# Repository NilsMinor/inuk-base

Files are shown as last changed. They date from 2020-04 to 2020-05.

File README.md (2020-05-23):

# Inuk base

This board is used in my open source smart garden light project. It is a 2 layer 70 mm x 100 mm design and serves as an NRF52 module carrier.
The board is powered by one 18650 rechargeable lipo and charged by an TP4056 module with a 6V solar cell. The light interface can controll up to five pwm controlled 3W LEDs.

#### Pin description

| Pin |  Function  | Note |
| ----- | :---: | ---: |
| P0.26 | LED D2 | high active |
| P0.27 | LED D3 | high active |
| P0.25 | BUTTON SW2 | low active |
| P0.06 |  UART TX | |
| P0.08 |  UART RX | |
| P0.07 |  UART RTS  | |
| P0.05 |  UART CTS  | |
| P0.02 | AIN0 | analog input - VBAT |
| P0.03 | AIN1 | analog input - VSOLAR |
| P0.04 | AIN2 | analog input |
| P0.28 | AIN4 | analog input - VLDR |
| P0.29 | AIN5 | analog input |
| P0.30 | AIN6 | analog input |
| P0.31 | AIN7 | analog input |
| P0.11 | LIO1 | pwm output led 1 |
| P0.12 | LIO2 | pwm output led 2 |
| P0.13 | LIO3 | pwm output led 3 |
| P0.14 | LIO4 | pwm output led 4 |
| P0.15 | LIO5 | pwm output led 5 |
| P0.16 | PIR INPUT  | pir input - high active |

#### Software

The inuk-base board is equipped with an E73-2G4M04S1B module that contains an nrf52832 SoC from nordic semiconductor. The nrf52832 bluetooth SoC comes with cortex-m4, 64K RAM and 512K ROM.

##### Note

It might happen that the E73 module comes with locked UICR. In order to unlock the flash download nrfjprog from nordic. Run the following command:

```
nrfjprog --recover
```

The output should then look like :

```
Recovering device. This operation might take 30s.
Erasing user code and UICR flash areas.
```

###### Click on the image below to see the gerber files

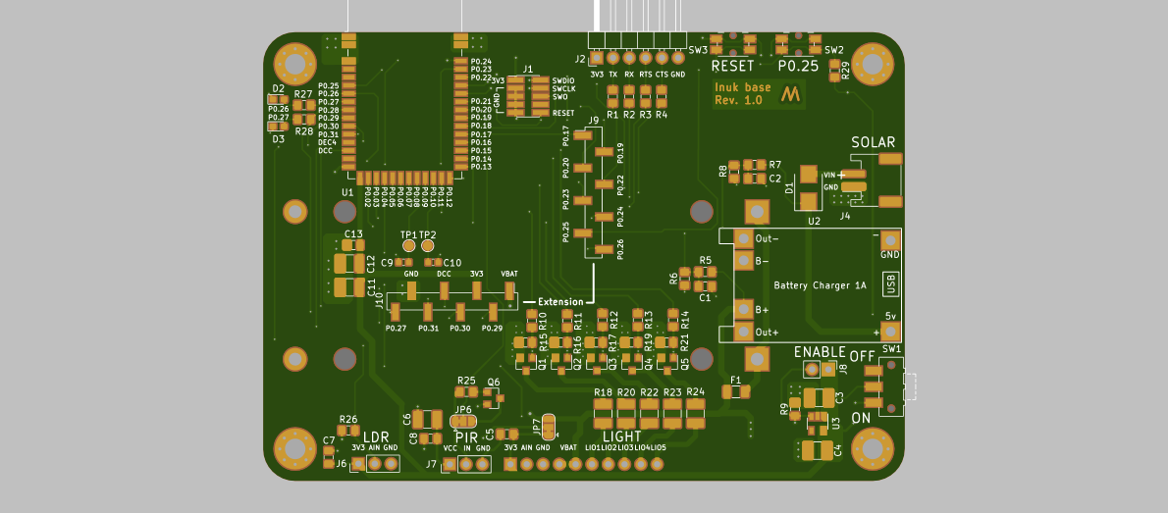
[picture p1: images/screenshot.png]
[](https://stackrate.de/viewer?stackId=Oa3Chhu8g)

###### Needs to be changed for version 2

- Remove direct GND connection poligons on E73 module. The direct GND connection is difficult to solder and needs
- Add (+) symbol to battery connector
- The DCDC on the NRF52 module is not supported, this should be changed in the next version.

##View in 3D
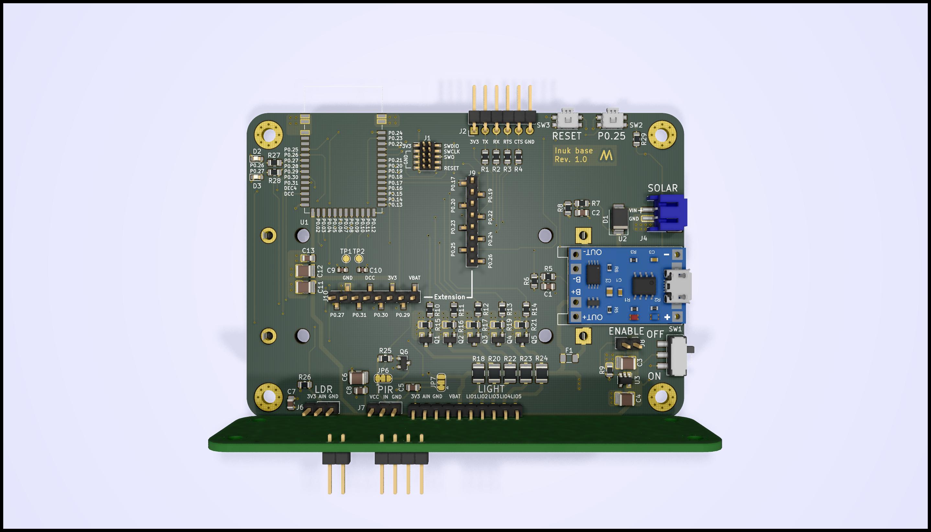
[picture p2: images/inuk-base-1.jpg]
3D Image 1

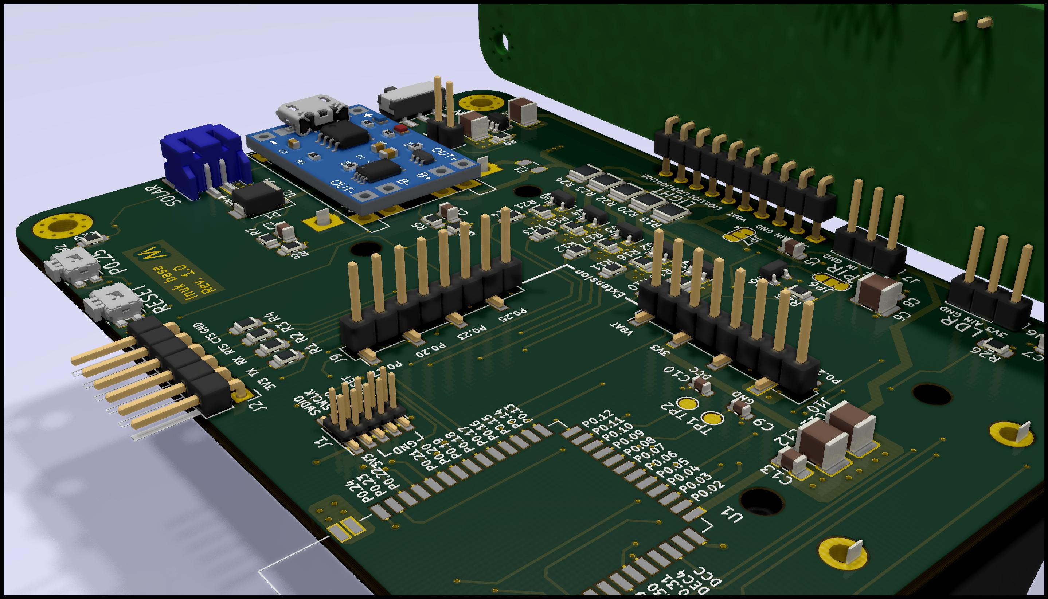
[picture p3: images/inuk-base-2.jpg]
3D Image 2

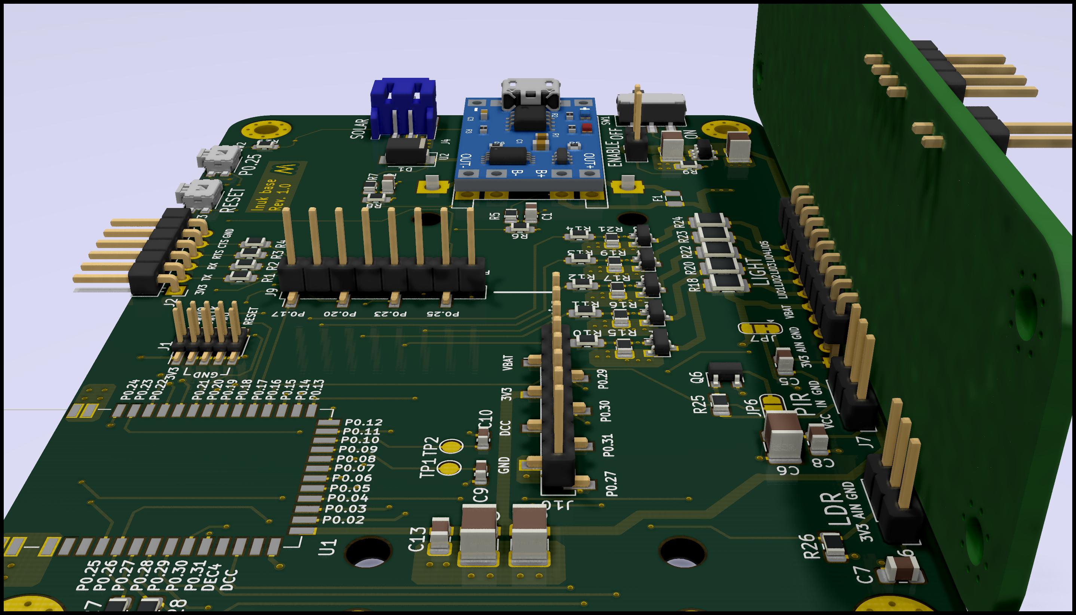
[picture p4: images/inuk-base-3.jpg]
3D Image 3


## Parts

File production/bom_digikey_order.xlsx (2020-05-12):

Comment | Designator | Footprint | Count | MPN
Fuse | F1 | Fuse:Fuse_1206_3216Metric | 1 | 0466002.NRHF
100R | R1,R2,R3,R4,R10,R11,R12,R13,R14 | Resistor_SMD:R_0805_2012Metric_Pad1.15x1.40mm_HandSolder | 9 | 0805W8F1000T5E
1k | R28,R27,R25 | Resistor_SMD:R_0805_2012Metric_Pad1.15x1.40mm_HandSolder | 3 | 0805W8F1001T5E
100k | R9,R16,R17,R19,R21,R15,R29,R26 | Resistor_SMD:R_0805_2012Metric_Pad1.15x1.40mm_HandSolder | 8 | 0805W8F1003T5E
2M | R6,R7 | Resistor_SMD:R_0805_2012Metric_Pad1.15x1.40mm_HandSolder | 2 | 0805W8F2004T5E
806k | R5,R8 | Resistor_SMD:R_0805_2012Metric_Pad1.15x1.40mm_HandSolder | 2 | 0805W8F8063T5E
0R5 | R24,R23,R22,R20,R18 | Resistor_SMD:R_1210_3225Metric_Pad1.42x2.65mm_HandSolder | 5 | 1210W3F500LT5E
LED | D3,D2 | LED_SMD:LED_0603_1608Metric_Pad1.05x0.95mm_HandSolder | 2 | 19-217/GHC-YR1S2/3T
AP2112K-3.3 | U3 | Package_TO_SOT_SMD:SOT-23-5 | 1 | AP2112K-3.3TRG1
B230-13-F | D1 | Diode_SMD:D_SMB | 1 | B230-13-F
1nF | C1,C2 | Capacitor_SMD:C_0805_2012Metric_Pad1.15x1.40mm_HandSolder | 2 | CL21B102KBCNNNC
100nF | C5,C13,C8,C7 | Capacitor_SMD:C_0805_2012Metric_Pad1.15x1.40mm_HandSolder | 4 | CL21B104KCFNNNE
10uF | C3,C4,C11,C12,C6 | Capacitor_SMD:C_1210_3225Metric_Pad1.42x2.65mm_HandSolder | 5 | CL31A106KBHNNNE
DMG3406L | Q2,Q3,Q4,Q5,Q1 | Package_TO_SOT_SMD:SOT-23 | 5 | DMG3420U-7
Battery_Cell | BT1,BT2 | Battery:BatteryHolder_MPD_BH-18650-PC2 | 1 | BK-18650-PC2
Conn_02x05_Odd_Even | J1 | Connector_PinHeader_1.27mm:PinHeader_2x05_P1.27mm_Vertical_SMD | 1 | FTSH-105-01-L-DV
Conn_01x06 | J2 | Connector_PinHeader_2.54mm:PinHeader_1x06_P2.54mm_Horizontal | 1 | 61301011121
Conn_01x02_Male | J4,J3 | Connector_JST:JST_PH_S2B-PH-SM4-TB_1x02-1MP_P2.00mm_Horizontal | 2 | S2B-PH-SM4-TB
Conn_01x08 | J5 | Custom:LED_shield | 1 | 61301211121
Conn_01x02_Male | J8 | Connector_PinHeader_2.54mm:PinHeader_1x02_P2.54mm_Vertical | 1 | 61301211121
Conn_01x08_Male | J9,J10 | Connector_PinHeader_2.54mm:PinHeader_1x08_P2.54mm_Vertical_SMD_Pin1Left | 1 | 61001618221 | 16 pin MPN selected to break
Conn_01x03_Male | J7,J6 | Connector_PinHeader_2.54mm:PinHeader_1x03_P2.54mm_Vertical | 2
SW_Push_SPDT | SW1 | Button_Switch_SMD:SW_SPDT_CK-JS102011SAQN | 1 | JS102011SAQN
SW_Push | SW3,SW2 | Button_Switch_SMD:Panasonic_EVQPUL_EVQPUC | 2 | EVQ-PUC02K

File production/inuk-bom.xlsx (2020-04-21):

Comment | Designator | Footprint | LCSC | LCSC | MPN
Fuse | F1 | Fuse:Fuse_1206_3216Metric |  | C3105 | 0466002.NRHF
100R | R1,R2,R3,R4,R10,R11,R12,R13,R14 | Resistor_SMD:R_0805_2012Metric_Pad1.15x1.40mm_HandSolder |  | C17408 | 0805W8F1000T5E
1k | R28,R27,R25 | Resistor_SMD:R_0805_2012Metric_Pad1.15x1.40mm_HandSolder |  | C17513 | 0805W8F1001T5E
100k | R9,R16,R17,R19,R21,R15,R29,R26 | Resistor_SMD:R_0805_2012Metric_Pad1.15x1.40mm_HandSolder |  | C17407 | 0805W8F1003T5E
2M | R6,R7 | Resistor_SMD:R_0805_2012Metric_Pad1.15x1.40mm_HandSolder |  | C26112 | 0805W8F2004T5E
806k | R5,R8 | Resistor_SMD:R_0805_2012Metric_Pad1.15x1.40mm_HandSolder |  | C63494 | 0805W8F8063T5E
0R5 | R24,R23,R22,R20,R18 | Resistor_SMD:R_1210_3225Metric_Pad1.42x2.65mm_HandSolder |  | C21355 | 1210W3F500LT5E
LED | D3,D2 | LED_SMD:LED_0603_1608Metric_Pad1.05x0.95mm_HandSolder |  | C72043 | 19-217/GHC-YR1S2/3T
AP2112K-3.3 | U3 | Package_TO_SOT_SMD:SOT-23-5 |  | C51118 | AP2112K-3.3TRG1
B230-13-F | D1 | Diode_SMD:D_SMB |  | C110482 | B230-13-F
1nF | C1,C2 | Capacitor_SMD:C_0805_2012Metric_Pad1.15x1.40mm_HandSolder |  | C46653 | CL21B102KBCNNNC
100nF | C5,C13,C8,C7 | Capacitor_SMD:C_0805_2012Metric_Pad1.15x1.40mm_HandSolder |  | C28233 | CL21B104KCFNNNE
10uF | C3,C4,C11,C12,C6 | Capacitor_SMD:C_1210_3225Metric_Pad1.42x2.65mm_HandSolder |  | C13585 | CL31A106KBHNNNE
DMG3406L | Q2,Q3,Q4,Q5,Q1 | Package_TO_SOT_SMD:SOT-23 |  | C154722 | DMG3420U-7
Battery_Cell | BT1,BT2 | Battery:BatteryHolder_MPD_BH-18650-PC2 |  |  | BK-18650-PC2
Conn_02x05_Odd_Even | J1 | Connector_PinHeader_1.27mm:PinHeader_2x05_P1.27mm_Vertical_SMD |  |  | FTSH-105-01-L-DV
Conn_01x06 | J2 | Connector_PinHeader_2.54mm:PinHeader_1x06_P2.54mm_Horizontal |  |  | 61301011121
Conn_01x02_Male | J4,J3 | Connector_JST:JST_PH_S2B-PH-SM4-TB_1x02-1MP_P2.00mm_Horizontal |  |  | S2B-PH-SM4-TB
Conn_01x08 | J5 | Custom:LED_shield |  |  | 61301211121
Conn_01x02_Male | J8 | Connector_PinHeader_2.54mm:PinHeader_1x02_P2.54mm_Vertical |  |  | 61301211121
Conn_01x08_Male | J9,J10 | Connector_PinHeader_2.54mm:PinHeader_1x08_P2.54mm_Vertical_SMD_Pin1Left |  |  | 61001618221 | 16 pin MPN selected to break
Conn_01x03_Male | J7,J6 | Connector_PinHeader_2.54mm:PinHeader_1x03_P2.54mm_Vertical
BC817 | Q6 | Package_TO_SOT_SMD:SOT-23 |  |  |  | NC
SW_Push_SPDT | SW1 | Button_Switch_SMD:SW_SPDT_CK-JS102011SAQN
SW_Push | SW3,SW2 | Button_Switch_SMD:Panasonic_EVQPUL_EVQPUC
TestPoint | TP1,TP2 | TestPoint:TestPoint_Pad_D1.5mm
E73-2G4M04S-52832 | U1 | RF_Module:E73-2G4M04S |  |  | ordered 7 | https://www.amazon.de/gp/product/B07WRKK521/ref=ppx_od_dt_b_asin_title_s00?ie=UTF8&psc=1
TP4056-module | U2 | Module:TP4056-module |  |  | ordered | https://www.ebay.de/itm/TP4056-USB-C-Neu-Li-Ion-Lademodul-5V-1A-18650-Laderegler-Charger-LIPO-Board/392521487361
Logo_NM | U4 | Custom:Logo_NM |  |  |  | NC
NC | C10,C9 | Capacitor_SMD:C_0603_1608Metric |  |  |  | NC
MountingHole | H4,H3,H2,H1 | MountingHole:MountingHole_3.2mm_M3_Pad_Via |  |  |  | NC
Jumper_NO_Small | JP1,JP2,JP3,JP4,JP5 | Jumper:SolderJumper-2_P1.3mm_Open_RoundedPad1.0x1.5mm |  |  |  | NC
SolderJumper_3_Bridged12 | JP7,JP6 | Jumper:SolderJumper-3_P1.3mm_Bridged12_RoundedPad1.0x1.5mm |  |  |  | NC
AM312 |  | PIR sensor extern | 1 |  | ordered 5 | https://www.amazon.de/gp/product/B07RJQMD9G/ref=ppx_yo_dt_b_asin_title_o00_s00?ie=UTF8&psc=1
3W power LEDs |  | High Power LEDs |  | 5 | ordered 100 | https://www.amazon.de/gp/product/B07BVTNS6Y/ref=ppx_yo_dt_b_asin_title_o00_s00?ie=UTF8&psc=1

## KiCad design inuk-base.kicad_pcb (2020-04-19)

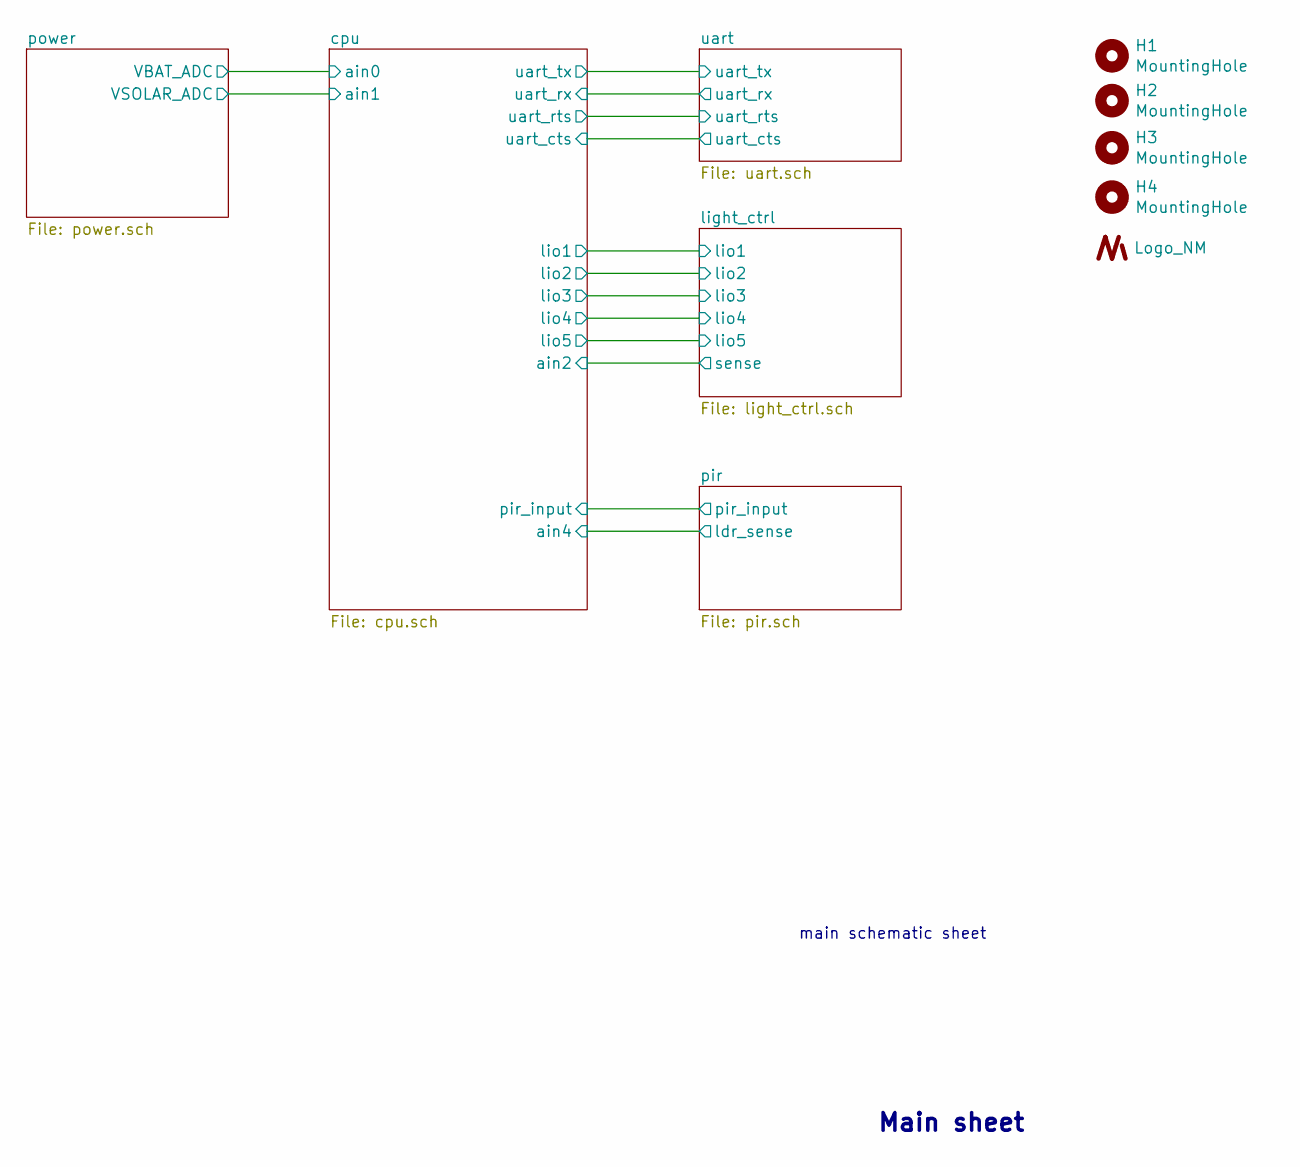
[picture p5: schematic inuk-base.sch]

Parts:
H1, H2, H3, H4: MountingHole; MountingHole_3.2mm_M3_Pad_Via
U4: Logo_NM

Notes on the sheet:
Main sheet
main schematic sheet

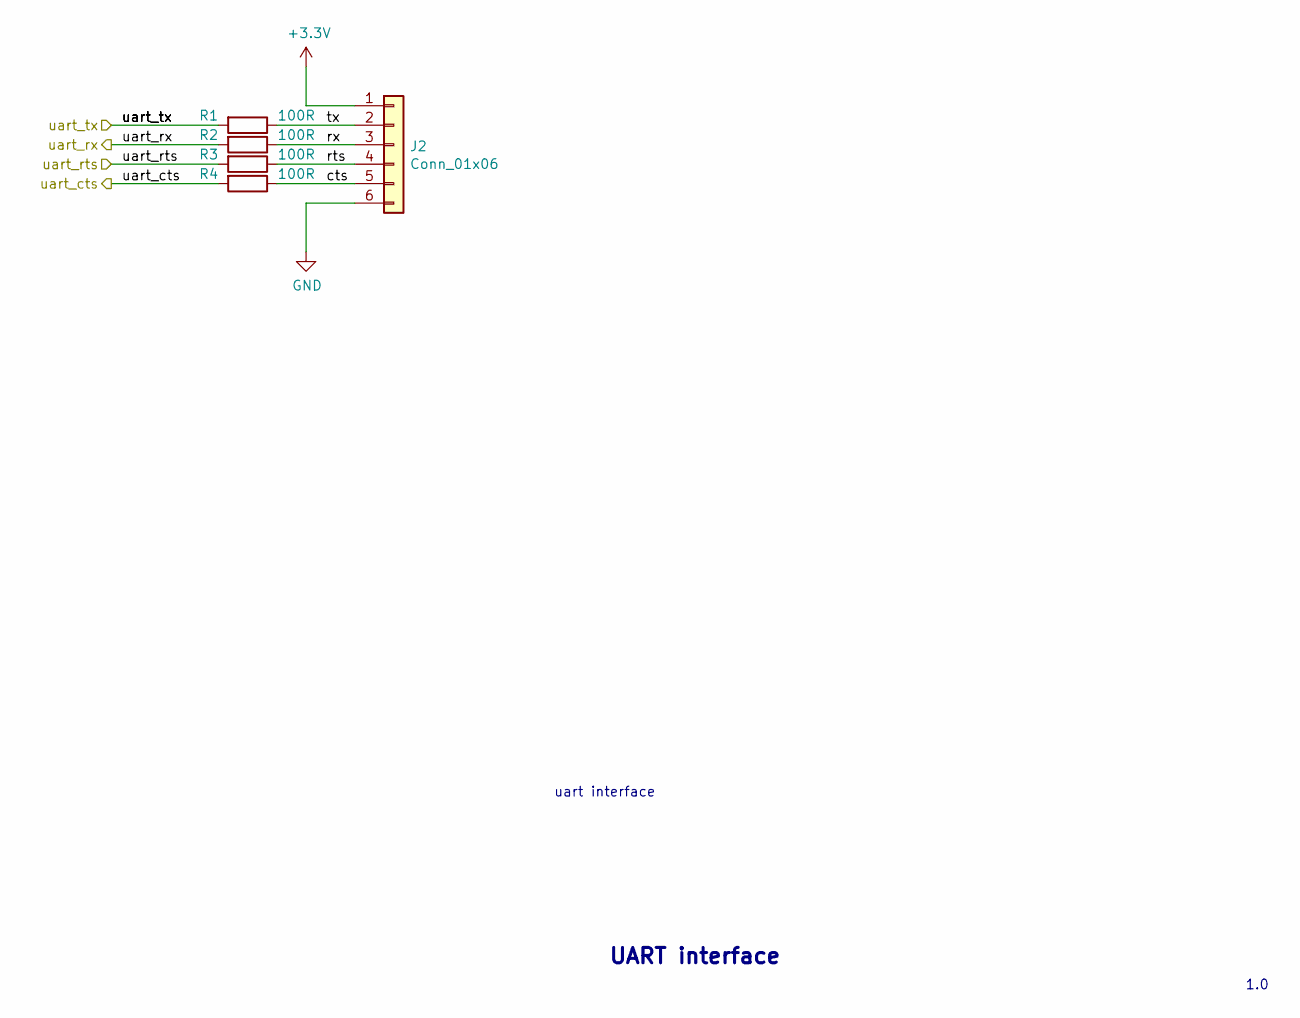
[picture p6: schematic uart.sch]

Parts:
J2: Conn_01x06; PinHeader_1x06_P2.54mm_Horizontal
R1, R2, R3, R4: 100R; R_0805_2012Metric_Pad1.15x1.40mm_HandSolder; MPN 0805W8F1000T5E; LCSC C17408

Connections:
+3V3: J2.1; also elsewhere on the board
/cpu/uart_cts: R4.2; also elsewhere on the board
/cpu/uart_rts: R3.2; also elsewhere on the board
/cpu/uart_rx: R2.2; also elsewhere on the board
/cpu/uart_tx: R1.2; also elsewhere on the board
/uart/cts: J2.5, R4.1
/uart/rts: J2.4, R3.1
/uart/rx: J2.3, R2.1
/uart/tx: J2.2, R1.1
GND: J2.6; also elsewhere on the board

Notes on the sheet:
UART interface
uart interface
1.0

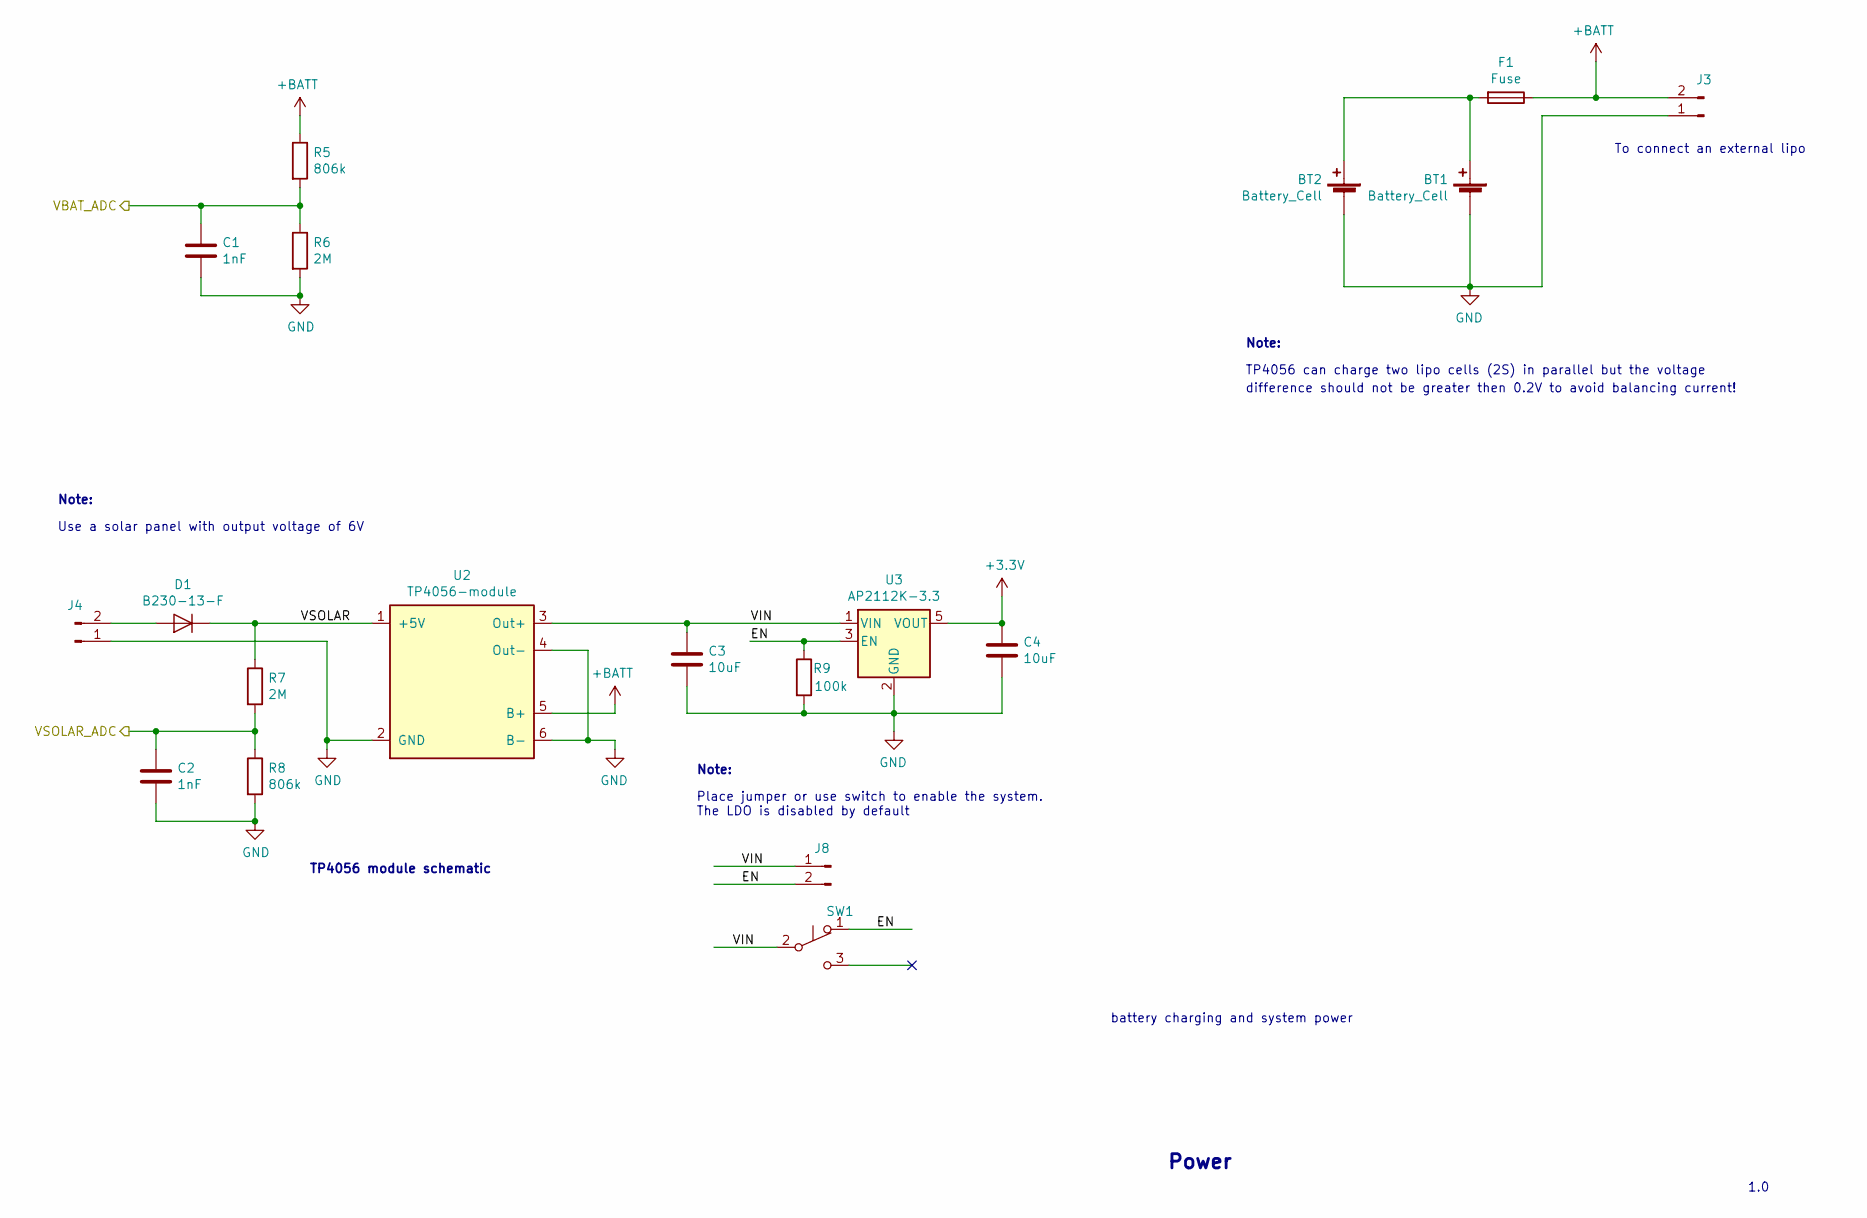
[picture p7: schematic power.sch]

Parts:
BT1, BT2: Battery_Cell; BatteryHolder_MPD_BH-18650-PC2
C1, C2: 1nF; C_0805_2012Metric_Pad1.15x1.40mm_HandSolder; MPN CL21B102KBCNNNC; LCSC C46653
C3, C4: 10uF; C_1210_3225Metric_Pad1.42x2.65mm_HandSolder; MPN CL31A106KBHNNNE; LCSC C13585
D1: B230-13-F; D_SMB; MPN B230-13-F; LCSC C110482
F1: Fuse; Fuse_1206_3216Metric; MPN 0466002.NRHF; LCSC C3105
J3, J4: Conn_01x02_Male; JST_PH_S2B-PH-SM4-TB_1x02-1MP_P2.00mm_Horizontal
J8: Conn_01x02_Male; PinHeader_1x02_P2.54mm_Vertical
R5, R8: 806k; R_0805_2012Metric_Pad1.15x1.40mm_HandSolder; MPN 0805W8F8063T5E; LCSC C63494
R6, R7: 2M; R_0805_2012Metric_Pad1.15x1.40mm_HandSolder; MPN 0805W8F2004T5E; LCSC C26112
R9: 100k; R_0805_2012Metric_Pad1.15x1.40mm_HandSolder; MPN 0805W8F1003T5E; LCSC C17407
SW1: SW_Push_SPDT; SW_SPDT_CK-JS102011SAQN
U2: TP4056-module
U3: AP2112K-3.3; SOT-23-5; MPN AP2112K-3.3TRG1; LCSC C51118

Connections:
+3V3: C4.1, U3.5 (VOUT); also elsewhere on the board
+BATT: F1.1, J3.2, R5.1, U2.5 (B+); also elsewhere on the board
/power/EN: J8.2, R9.1, SW1.1 (A), U3.3 (EN)
/power/VBAT_ADC: C1.1, R5.2, R6.1; also elsewhere on the board
/power/VIN: C3.1, J8.1, SW1.2 (B), U2.3 (Out+), U3.1 (VIN)
/power/VSOLAR: D1.1 (K), R7.1, U2.1 (+5V)
/power/VSOLAR_ADC: C2.1, R7.2, R8.1; also elsewhere on the board
GND: BT1.2 (-), BT2.2 (-), C1.2, C2.2, C3.2, C4.2, J3.1, J4.1, R6.2, R8.2, R9.2, U2.2 (GND), U2.4 (Out-), U2.6 (B-), U3.2 (GND); also elsewhere on the board
unnamed: BT1.1 (+), BT2.1 (+), F1.2
unnamed: D1.2 (A), J4.2

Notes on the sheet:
TP4056 can charge two lipo cells (2S) in parallel but the voltage
difference should not be greater then 0.2V to avoid balancing current!
Note:
Place jumper or use switch to enable the system. The LDO is disabled by default
TP4056 module schematic
Use a solar panel with output voltage of 6V
Power
battery charging and system power
To connect an external lipo
1.0

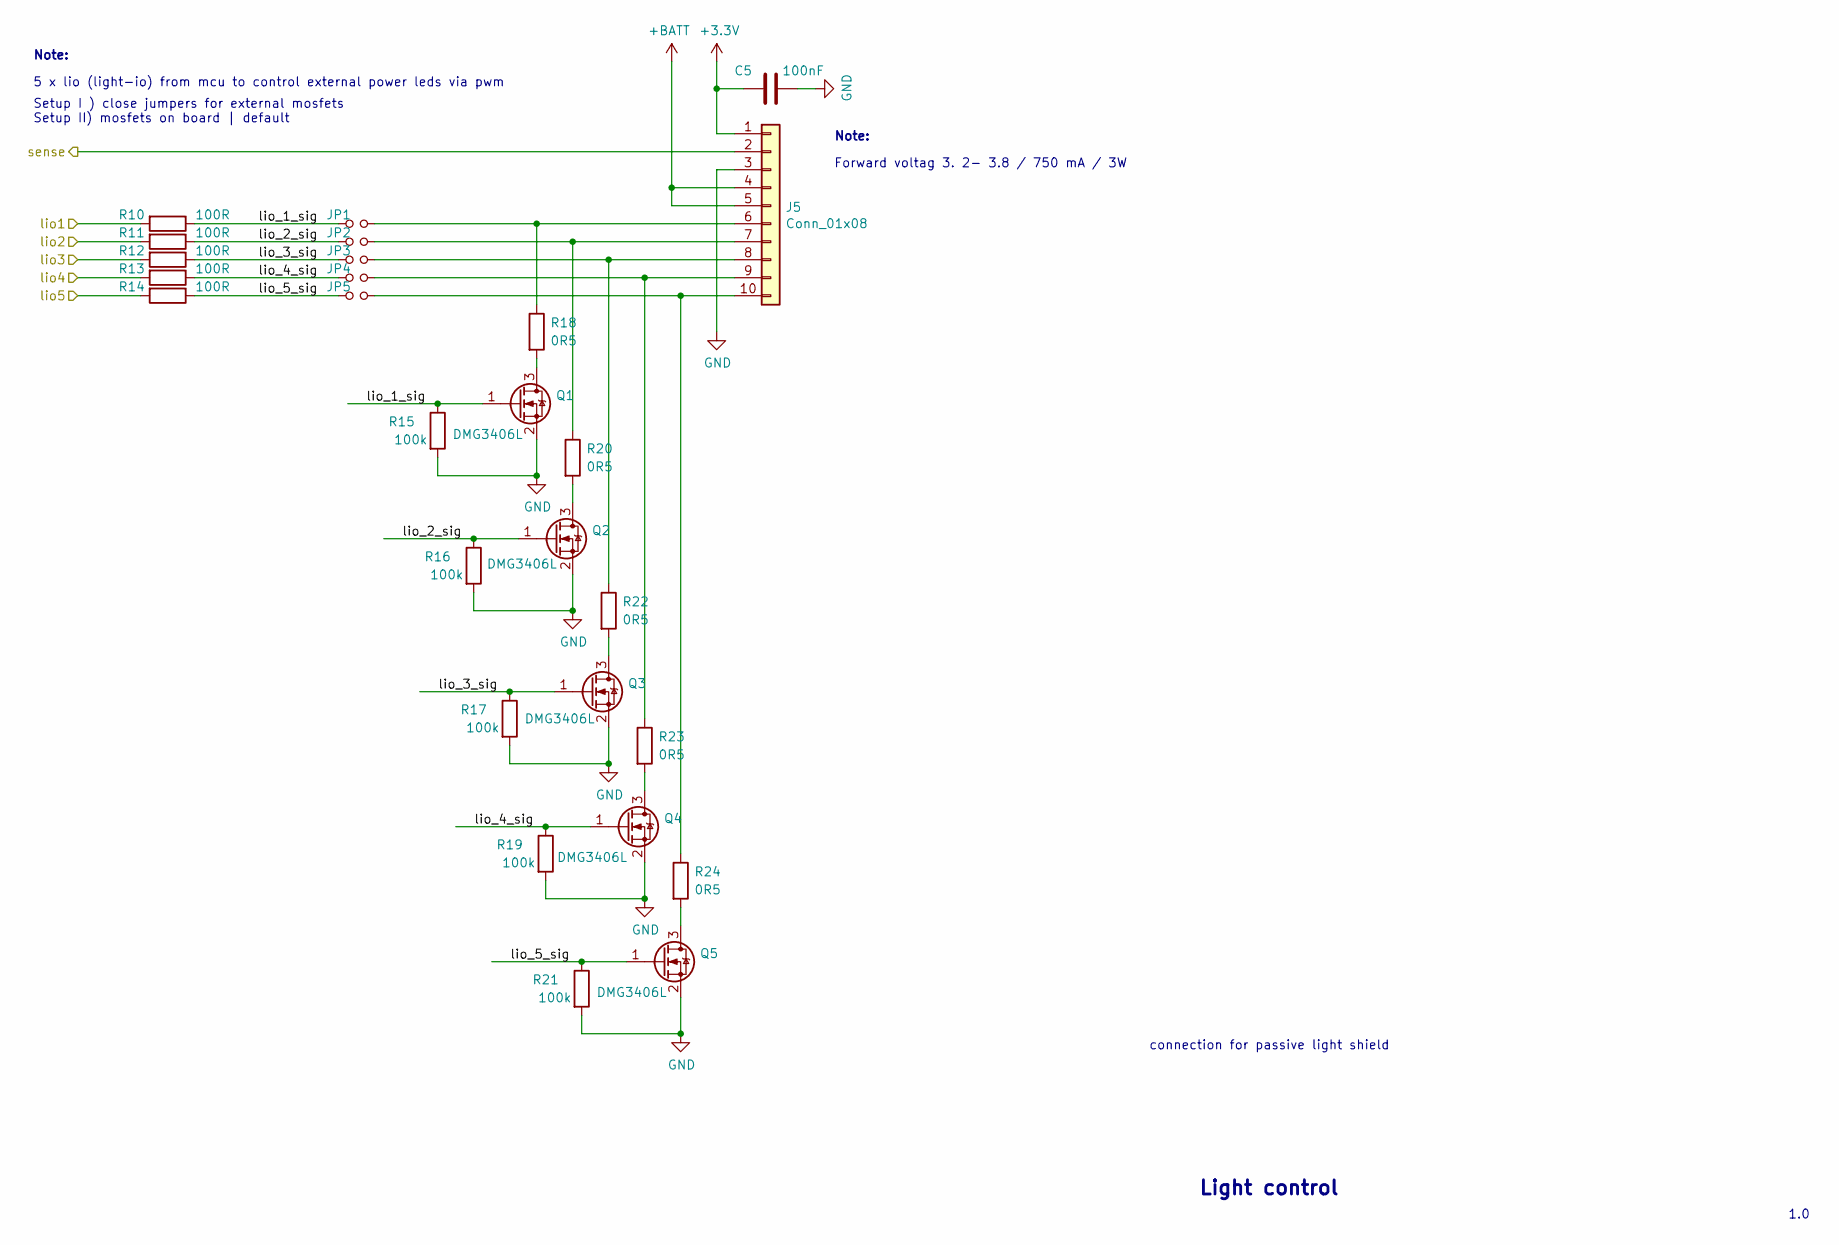
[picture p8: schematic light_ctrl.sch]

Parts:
C5: 100nF; C_0805_2012Metric_Pad1.15x1.40mm_HandSolder; MPN CL21B104KCFNNNE; LCSC C28233
J5: Conn_01x08; LED_shield
JP1, JP2, JP3, JP4, JP5: Jumper_NO_Small; SolderJumper-2_P1.3mm_Open_RoundedPad1.0x1.5mm
Q1, Q2, Q3, Q4, Q5: DMG3406L; SOT-23; MPN DMG3420U-7; LCSC C154722
R10, R11, R12, R13, R14: 100R; R_0805_2012Metric_Pad1.15x1.40mm_HandSolder; MPN 0805W8F1000T5E; LCSC C17408
R15, R16, R17, R19, R21: 100k; R_0805_2012Metric_Pad1.15x1.40mm_HandSolder; MPN 0805W8F1003T5E; LCSC C17407
R18, R20, R22, R23, R24: 0R5; R_1210_3225Metric_Pad1.42x2.65mm_HandSolder; MPN 1210W3F500LT5E; LCSC C21355

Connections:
+3V3: C5.1, J5.1; also elsewhere on the board
+BATT: J5.4, J5.5; also elsewhere on the board
/cpu/ain2: J5.2; also elsewhere on the board
/cpu/lio1: R10.2; also elsewhere on the board
/cpu/lio2: R11.2; also elsewhere on the board
/cpu/lio3: R12.2; also elsewhere on the board
/cpu/lio4: R13.2; also elsewhere on the board
/cpu/lio5: R14.2; also elsewhere on the board
/light_ctrl/lio_1_sig: JP1.1, Q1.1 (G), R10.1, R15.1
/light_ctrl/lio_2_sig: JP2.1, Q2.1 (G), R11.1, R16.1
/light_ctrl/lio_3_sig: JP3.1, Q3.1 (G), R12.1, R17.1
/light_ctrl/lio_4_sig: JP4.1, Q4.1 (G), R13.1, R19.1
/light_ctrl/lio_5_sig: JP5.1, Q5.1 (G), R14.1, R21.1
GND: C5.2, J5.3, Q1.2 (S), Q2.2 (S), Q3.2 (S), Q4.2 (S), Q5.2 (S), R15.2, R16.2, R17.2, R19.2, R21.2; also elsewhere on the board
unnamed: J5.6, JP1.2, R18.1
unnamed: J5.7, JP2.2, R20.1
unnamed: J5.8, JP3.2, R22.1
unnamed: J5.9, JP4.2, R23.1
unnamed: J5.10, JP5.2, R24.1
unnamed: Q1.3 (D), R18.2
unnamed: Q2.3 (D), R20.2
unnamed: Q3.3 (D), R22.2
unnamed: Q4.3 (D), R23.2
unnamed: Q5.3 (D), R24.2

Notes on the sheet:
5 x lio (light-io) from mcu to control external power leds via pwm
Note:
Forward voltag 3. 2- 3.8 / 750 mA / 3W
Setup I ) close jumpers for external mosfets Setup II) mosfets on board | default
Light control
connection for passive light shield
1.0

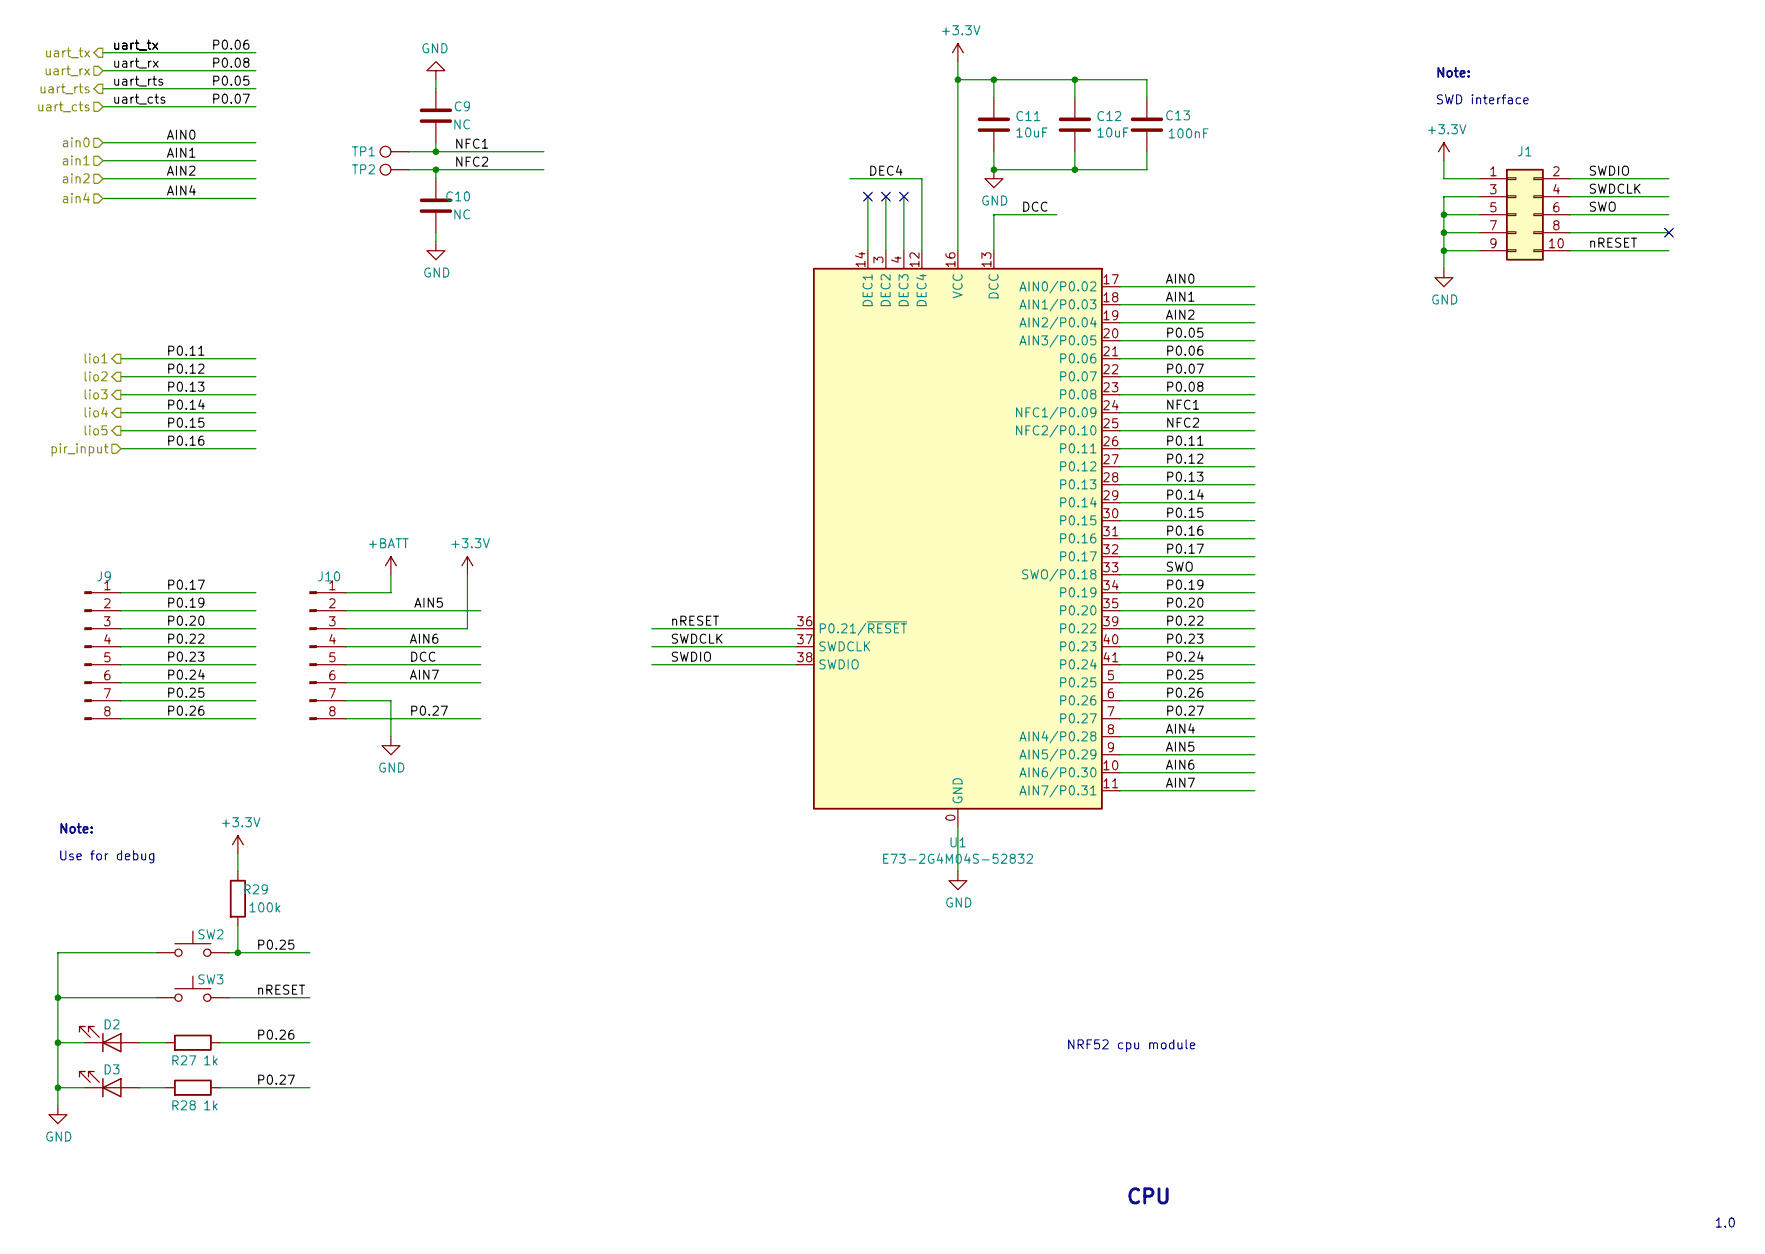
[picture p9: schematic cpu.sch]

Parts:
C9, C10: NC; C_0603_1608Metric
C11, C12: 10uF; C_1210_3225Metric_Pad1.42x2.65mm_HandSolder; MPN CL31A106KBHNNNE; LCSC C13585
C13: 100nF; C_0805_2012Metric_Pad1.15x1.40mm_HandSolder; MPN CL21B104KCFNNNE; LCSC C28233
D2, D3: LED; LED_0603_1608Metric_Pad1.05x0.95mm_HandSolder; MPN 19-217/GHC-YR1S2/3T; LCSC C72043
J1: Conn_02x05_Odd_Even; PinHeader_2x05_P1.27mm_Vertical_SMD
J9, J10: Conn_01x08_Male; PinHeader_1x08_P2.54mm_Vertical_SMD_Pin1Left
R27, R28: 1k; R_0805_2012Metric_Pad1.15x1.40mm_HandSolder; MPN 0805W8F1001T5E; LCSC C17513
R29: 100k; R_0805_2012Metric_Pad1.15x1.40mm_HandSolder; MPN 0805W8F1003T5E; LCSC C17407
SW2, SW3: SW_Push; Panasonic_EVQPUL_EVQPUC
TP1, TP2: TestPoint; TestPoint_Pad_D1.5mm
U1: E73-2G4M04S-52832; E73-2G4M04S

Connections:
+3V3: C11.1, C12.1, C13.2, J1.1, J10.3, R29.1, U1.16 (VCC); also elsewhere on the board
+BATT: J10.1; also elsewhere on the board
/cpu/AIN5: J10.2, U1.9 (AIN5/P0.29)
/cpu/AIN6: J10.4, U1.10 (AIN6/P0.30)
/cpu/AIN7: J10.6, U1.11 (AIN7/P0.31)
/cpu/DCC: J10.5, U1.13 (DCC)
/cpu/DEC4: U1.12 (DEC4)
/cpu/NFC1: C9.2, TP1.1, U1.24 (NFC1/P0.09)
/cpu/NFC2: C10.2, TP2.1, U1.25 (NFC2/P0.10)
/cpu/P0.17: J9.1, U1.32 (P0.17)
/cpu/P0.19: J9.2, U1.34 (P0.19)
/cpu/P0.20: J9.3, U1.35 (P0.20)
/cpu/P0.22: J9.4, U1.39 (P0.22)
/cpu/P0.23: J9.5, U1.40 (P0.23)
/cpu/P0.24: J9.6, U1.41 (P0.24)
/cpu/P0.25: J9.7, R29.2, SW2.2, U1.5 (P0.25)
/cpu/P0.26: J9.8, R27.1, U1.6 (P0.26)
/cpu/P0.27: J10.8, R28.1, U1.7 (P0.27)
/cpu/SWDCLK: J1.4, U1.37 (SWDCLK)
/cpu/SWDIO: J1.2, U1.38 (SWDIO)
/cpu/SWO: J1.6, U1.33 (SWO/P0.18)
/cpu/ain2: U1.19 (AIN2/P0.04); also elsewhere on the board
/cpu/ain4: U1.8 (AIN4/P0.28); also elsewhere on the board
/cpu/lio1: U1.26 (P0.11); also elsewhere on the board
/cpu/lio2: U1.27 (P0.12); also elsewhere on the board
/cpu/lio3: U1.28 (P0.13); also elsewhere on the board
/cpu/lio4: U1.29 (P0.14); also elsewhere on the board
/cpu/lio5: U1.30 (P0.15); also elsewhere on the board
/cpu/nRESET: J1.10, SW3.2, U1.36 (P0.21/~RESET)
/cpu/pir_input: U1.31 (P0.16); also elsewhere on the board
/cpu/uart_cts: U1.22 (P0.07); also elsewhere on the board
/cpu/uart_rts: U1.20 (AIN3/P0.05); also elsewhere on the board
/cpu/uart_rx: U1.23 (P0.08); also elsewhere on the board
/cpu/uart_tx: U1.21 (P0.06); also elsewhere on the board
/power/VBAT_ADC: U1.17 (AIN0/P0.02); also elsewhere on the board
/power/VSOLAR_ADC: U1.18 (AIN1/P0.03); also elsewhere on the board
GND: C9.1, C10.1, C11.2, C12.2, C13.1, D2.1 (K), D3.1 (K), J1.3, J1.5, J1.7, J1.9, J10.7, SW2.1, SW3.1, U1.0 (GND), U1.1 (GND), U1.2 (GND), U1.15 (GND), U1.42 (GND), U1.43 (GND); also elsewhere on the board
unnamed: D2.2 (A), R27.2
unnamed: D3.2 (A), R28.2

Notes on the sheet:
SWD interface
Note:
Use for debug
CPU
NRF52 cpu module
1.0

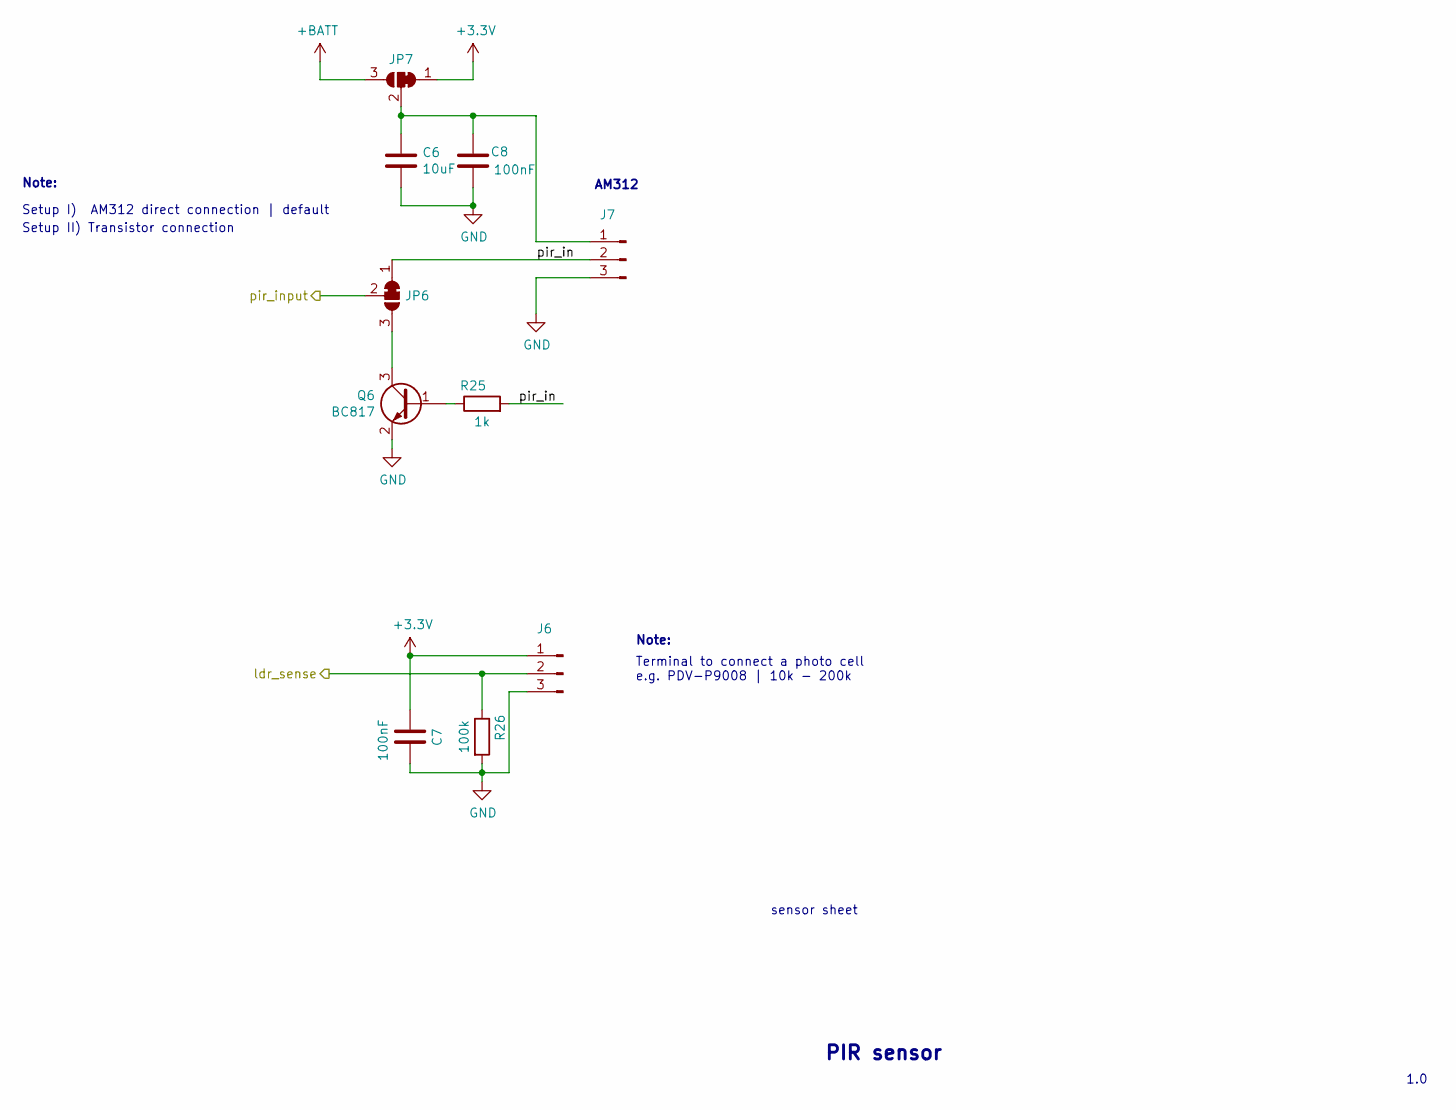
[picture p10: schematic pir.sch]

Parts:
C6: 10uF; C_1210_3225Metric_Pad1.42x2.65mm_HandSolder; MPN CL31A106KBHNNNE; LCSC C13585
C7, C8: 100nF; C_0805_2012Metric_Pad1.15x1.40mm_HandSolder; MPN CL21B104KCFNNNE; LCSC C28233
J6, J7: Conn_01x03_Male; PinHeader_1x03_P2.54mm_Vertical
JP6, JP7: SolderJumper_3_Bridged12; SolderJumper-3_P1.3mm_Bridged12_RoundedPad1.0x1.5mm
Q6: BC817; SOT-23
R25: 1k; R_0805_2012Metric_Pad1.15x1.40mm_HandSolder; MPN 0805W8F1001T5E; LCSC C17513
R26: 100k; R_0805_2012Metric_Pad1.15x1.40mm_HandSolder; MPN 0805W8F1003T5E; LCSC C17407

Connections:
+3V3: C7.2, J6.1, JP7.1 (A); also elsewhere on the board
+BATT: JP7.3 (B); also elsewhere on the board
/cpu/ain4: J6.2, R26.1; also elsewhere on the board
/cpu/pir_input: JP6.2 (C); also elsewhere on the board
/pir/pir_in: J7.2, JP6.1 (A), R25.2
GND: C6.2, C7.1, C8.1, J6.3, J7.3, Q6.2 (E), R26.2; also elsewhere on the board
unnamed: C6.1, C8.2, J7.1, JP7.2 (C)
unnamed: JP6.3 (B), Q6.3 (C)
unnamed: Q6.1 (B), R25.1

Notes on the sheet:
Setup I) AM312 direct connection | default
Note:
Setup II) Transistor connection
AM312
Terminal to connect a photo cell e.g. PDV-P9008 | 10k - 200k
PIR sensor
sensor sheet
1.0

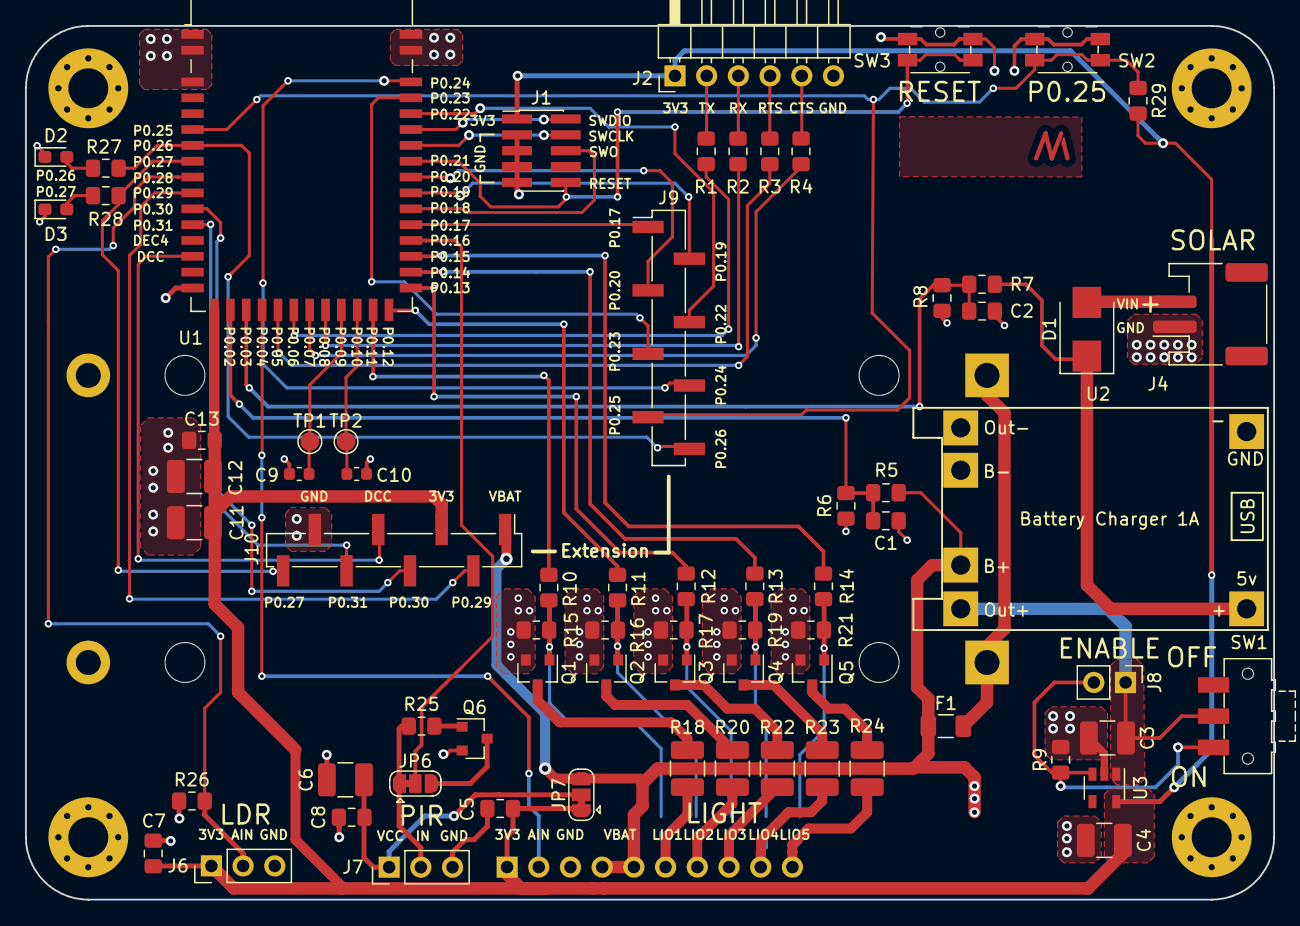
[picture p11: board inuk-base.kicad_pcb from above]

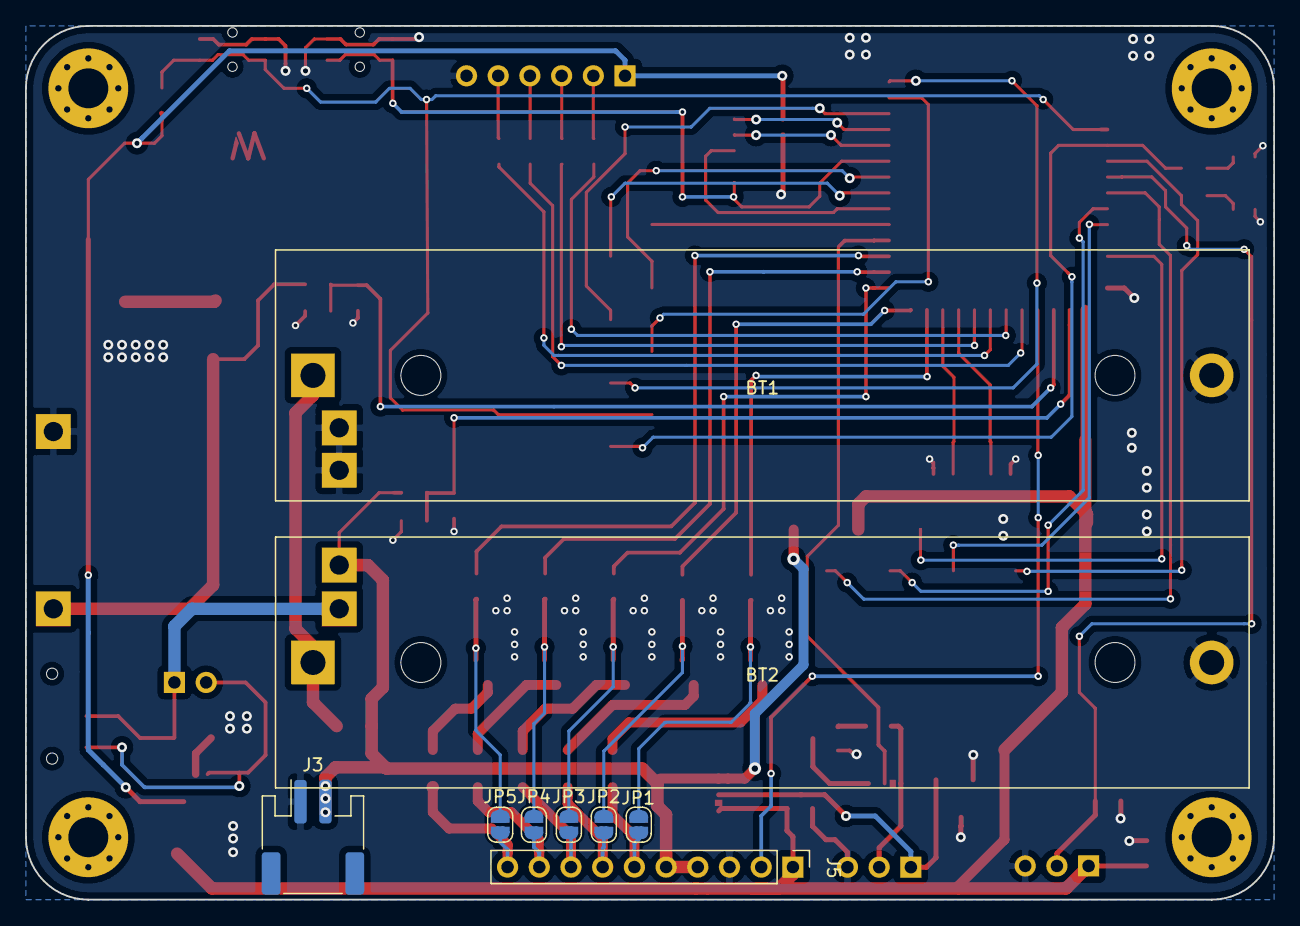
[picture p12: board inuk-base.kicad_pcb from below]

Board: 2 copper layers, 100.0 x 70.0 mm, 84 parts (9 on the bottom side), 66 nets.

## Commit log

2020-03-22 added TP4056 module
    [cpu.sch, inuk-base.kicad_pcb, power.sch]
2020-03-22 pcb layout
    [inuk-base.kicad_pcb, inuk-base.sch, power.sch]
2020-03-31 created light control schematic
    [cpu.sch, inuk-base.kicad_pcb, inuk-base.sch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]
2020-04-12 added more circuit parts + new step files
    [cpu.sch, inuk-base.kicad_pcb, inuk-base.sch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]
2020-04-13 started pcb routing
    [cpu.sch, inuk-base.kicad_pcb, inuk-base.sch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]
2020-04-14 more layout + resized pcb to 100 x 80
    [cpu.sch, inuk-base.kicad_pcb]
2020-04-15 changed pcb size to 100 x 70 and made progress on layout
    [cpu.sch, inuk-base.kicad_pcb]
2020-04-17 layout and more silk informations
    [cpu.sch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]
2020-04-19 finished layout, created production files and added readme
    [cpu.sch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]
2020-04-21 added bom
    [inuk-bom.xlsx]
2020-05-12 added README with programming info
    [bom_digikey_order.xlsx]
2020-05-23 more pin info
